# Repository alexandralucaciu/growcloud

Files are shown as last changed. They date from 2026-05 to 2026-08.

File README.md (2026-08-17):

# GrowCloud: Smart IoT Microclimate Monitoring System

An end-to-end IoT system designed to monitor and optimize the microclimate of indoor houseplants (*Spathiphyllum*). The project integrates a battery-powered edge sensing node, ThingsBoard Cloud telemetry, serverless proxy functions, and a responsive React web dashboard.

*Bachelor's Thesis Project — Politehnica University of Timișoara, Systems Engineering (Automation and Applied Informatics), July 2026.*
*Author: Alexandra Buhai (Lucaciu) | Coordinator: Ș.l.dr.ing. Paul Negîrla*

---

## System Architecture

The project follows a three-tier architecture:

1. **Edge Node (ESP32-S2 Mini):** Acquires sensor data (temperature, air humidity, ambient light, and capacitive soil moisture), provides local visual feedback via an OLED display, and transmits telemetry over MQTT every 2 hours (or on-demand via push button).
2. **Cloud Backend (ThingsBoard Cloud):** Collects and persists time-series telemetry data and manages historical logs.
3. **Serverless Layer & Web Application (React / Vite + Vercel):**
   - **Secure Serverless Proxy:** Isolates ThingsBoard credentials within backend environment variables (`process.env`). The client-side application queries internal endpoints (`/api/telemetry/latest`), preventing credential leakage.
   - **Vercel KV (Redis):** Handles persistent state tracking across serverless invocations (e.g., 24-hour soil oversaturation detection, daily user streak, and anti-duplicate email alert throttling).
   - **Automated Alerts:** Cron functions notify users via email (Resend API) when the device goes offline or critical thresholds are breached.
   - **Web Dashboard:** Displays live vs. stale data indicators, plant health status (normal, warning, critical), customized watering guides, and historical charts.

---

## Hardware Components & Enclosure

- **Microcontroller:** ESP32-S2 Mini (MicroPython runtime)
- **Environmental Sensor:** DHT22 (Air Temperature & Humidity)
- **Light Sensor:** BH1750 (I2C ambient light sensor in Lux)
- **Soil Moisture Sensor:** Capacitive Soil Moisture Sensor v2.0 (corrosion-resistant analog probe)
- **Display:** 1.3" I2C OLED Display (SH1106 driver)
- **Power Management:** 3.7V 2000 mAh Li-Po battery, TP4056 USB-C charging/protection module, 3.7V-to-5V step-up boost converter, and mechanical toggle switch
- **Enclosure:** Custom 3D-printed two-piece enclosure designed and sliced for optimal component placement and thermal isolation

---

## Firmware Features (MicroPython)

- **Digital Filtering & Soil Calibration:** 50-sample moving average filter on analog readings to suppress electrical noise. Maps inverted raw ADC values (8191 for dry air, 3320 for saturated water) to a 0–100% moisture scale.
- **Fault-Tolerant Acquisition:** Implements sentinel error values (-1) if a sensor fails, ensuring uninterrupted MQTT transmission cycles.
- **Dual Acquisition Modes:** Automated background interval transmission (every 2 hours) and instant on-demand reading triggered by a hardware button.

---

## Repository Structure

```
├── api/
│   ├── check-inactivity.js       # Vercel cron function for inactivity/offline email alerts
│   └── telemetry/
│       └── latest.js             # Secure backend proxy to ThingsBoard API
├── firmware/
│   ├── boot.py                   # Wi-Fi initialization
│   ├── main.py                   # Main sampling loop, digital filtering, and MQTT client
│   ├── sh1106.py                 # OLED display driver
│   ├── sprites.py                # Graphical UI assets for the OLED screen
│   └── umqttsimple.py            # Lightweight MQTT implementation
├── src/                          # React web application (UI components, hooks, charts)
├── public/                       # Static web assets
├── index.html                    # Web entry point
├── vercel.json                   # Vercel deployment and cron configuration
└── vite.config.js                # Vite build configuration
```

---

## Hardware / 3D Models

The enclosure and battery holder were custom-designed and sliced for optimal component placement and thermal isolation. Project files (`.3mf`, editable in Cura, PrusaSlicer, or Bambu Studio) are available in [`3d-models/`](./3d-models):

- `project base.3mf` / `project body.3mf` / `project top.3mf` — the three-part enclosure
- `battery-box1.3mf` / `battery-box2.3mf` — battery compartment

---

## Gallery & Demo

<p align="center">
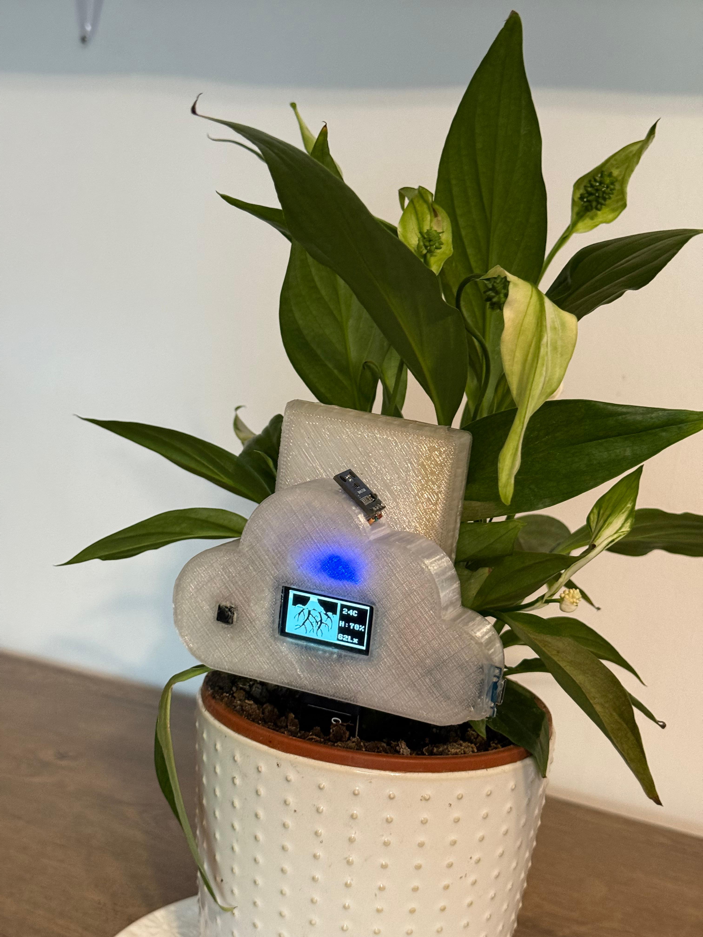
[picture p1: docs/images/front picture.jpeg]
GrowCloud device - front view
  
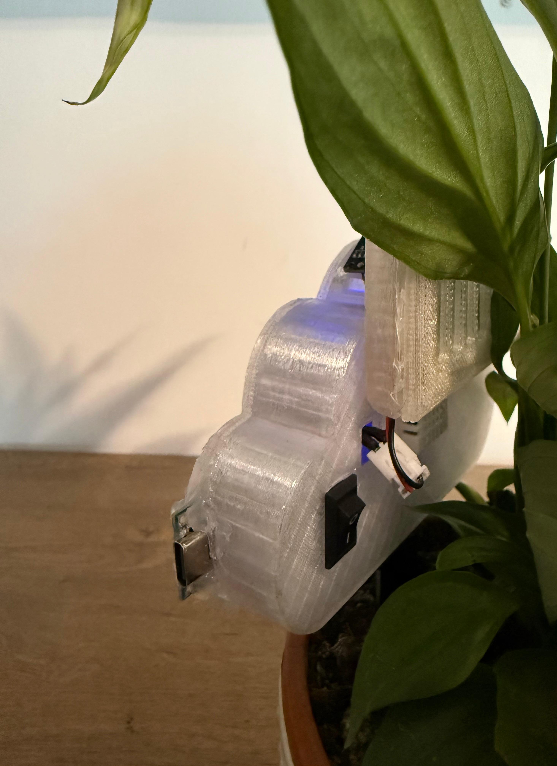
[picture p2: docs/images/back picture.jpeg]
GrowCloud device - back view
  
</p>

📹 **Demo video:** hosted on OneDrive due to file size — see [docs/video/Lucaciu_Alexandra_Video_AIA_Licenta.pdf](./docs/video/Lucaciu_Alexandra_Video_AIA_Licenta.pdf) for the link.

---

## Getting Started

### 1. Firmware Setup (ESP32-S2 Mini)

1. Flash MicroPython firmware onto the ESP32-S2 Mini using Thonny IDE or `esptool`.
2. Open `firmware/boot.py` and configure your local Wi-Fi credentials:

   ```python
   SSID = "YOUR_WIFI_SSID"
   PASS = "YOUR_WIFI_PASSWORD"
   ```

3. Open `firmware/main.py` and insert your ThingsBoard device token:

   ```python
   ACCESS_TOKEN = "YOUR_THINGSBOARD_TOKEN"
   ```

4. Upload all files from the `firmware/` directory directly to the root of the ESP32 filesystem.
5. The device connects to Wi-Fi on boot and begins periodic telemetry reporting.

### 2. Web Application Setup (Local Development)

**Prerequisites**

- Node.js 18+ (tested on Node 22)
- npm

**Environment Variables**

Create a `.env` file in the root directory and configure the required keys:

```
TB_SERVER_URL=https://thingsboard.cloud
TB_USERNAME=your_thingsboard_username
TB_PASSWORD=your_thingsboard_password
TB_DEVICE_ID=your_device_id
RESEND_API_KEY=your_resend_api_key
USER_ALERT_EMAIL=user@example.com
CRON_SECRET=your_secure_cron_secret
VERCEL_PROJECT_URL=http://localhost:5173
```

**Installation and Execution**

```bash
# Install dependencies
npm install

# Start development server
npm run dev

# Build for production
npm run build
```

The application will be accessible locally at `http://localhost:5173`.

---

## Deployment

The web dashboard and serverless endpoints are configured for continuous deployment on Vercel. Environment variables are managed securely through the Vercel project dashboard, and cron schedules in `vercel.json` run automated inactivity and health checks without requiring dedicated server infrastructure.

---

## License

This project is licensed under the MIT License — see the [LICENSE](./LICENSE) file for details.

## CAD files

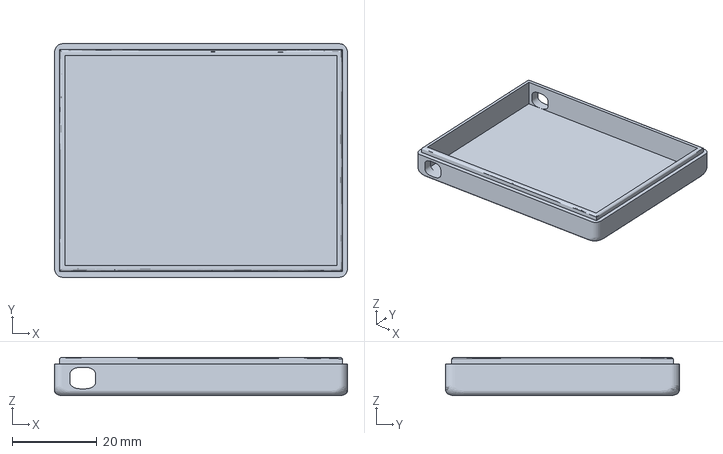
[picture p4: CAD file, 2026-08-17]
3d-models/battery-box1.3mf
69.0 x 55.0 x 9.00 mm

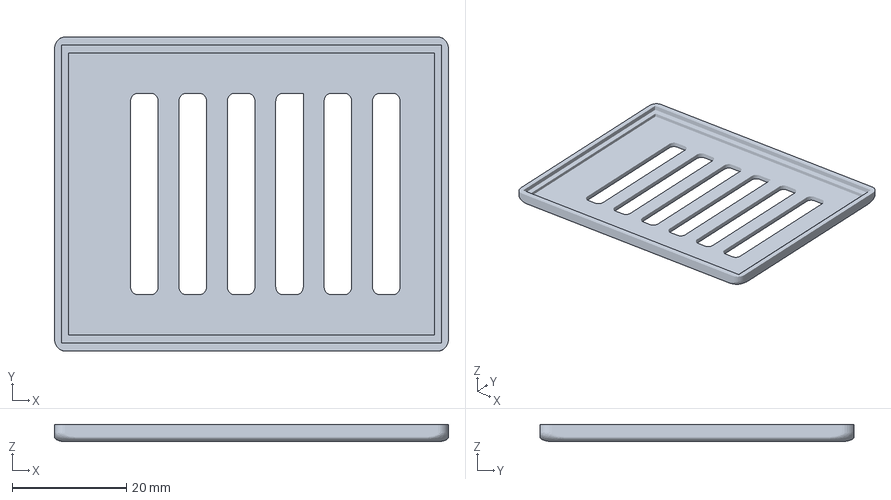
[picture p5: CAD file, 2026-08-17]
3d-models/battery-box2.3mf
69.0 x 55.0 x 3.00 mm

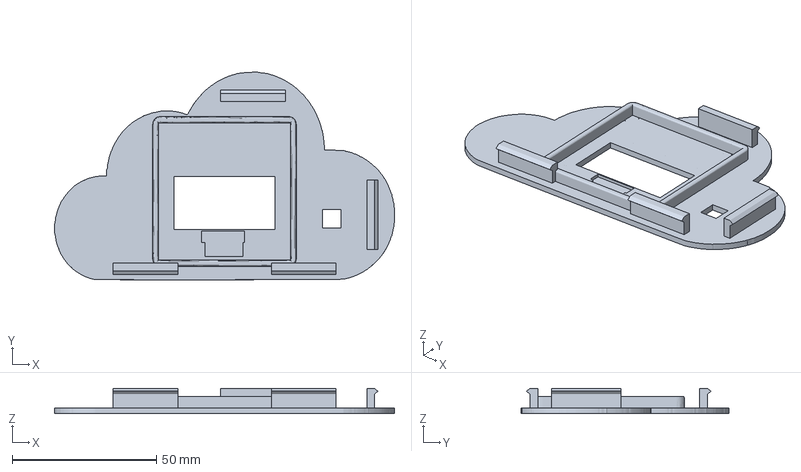
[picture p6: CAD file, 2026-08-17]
3d-models/project top.3mf
117.7 x 71.9 x 8.75 mm

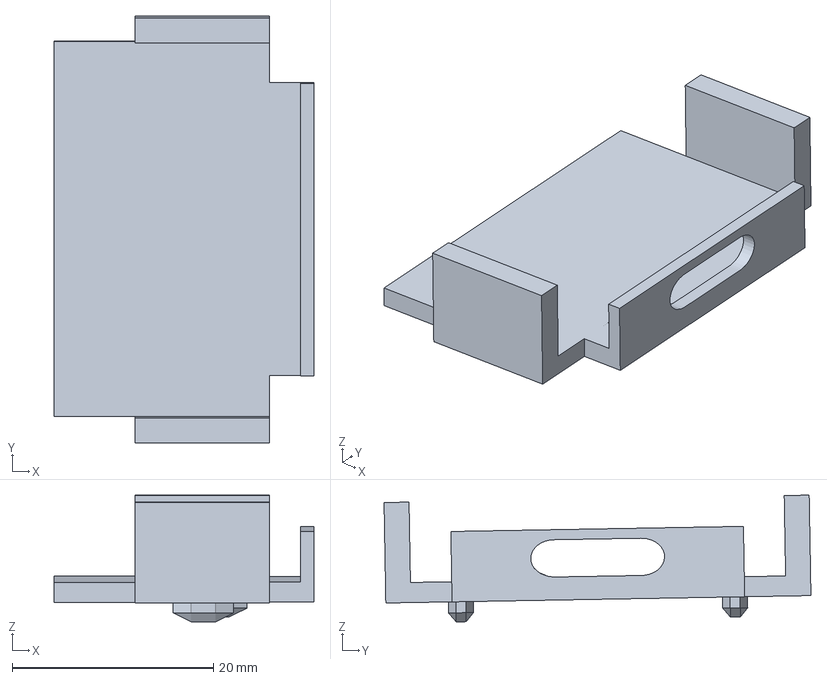
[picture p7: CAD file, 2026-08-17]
3d-models/project base.3mf
25.9 x 42.5 x 12.6 mm

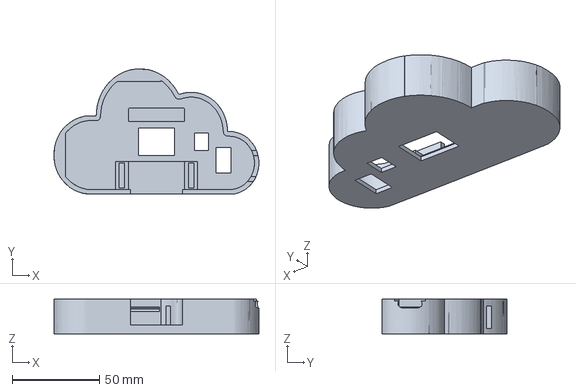
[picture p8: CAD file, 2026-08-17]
3d-models/project body.3mf
117.7 x 71.9 x 20.0 mm

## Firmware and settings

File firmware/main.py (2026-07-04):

from machine import Pin, I2C, ADC
import sh1106
from framebuf import FrameBuffer, MONO_HLSB
from sprites import root
from umqttsimple import MQTTClient
import time
import dht

# ---------------- Configurare ThingsBoard ----------------
TB_SERVER = "eu.thingsboard.cloud"
ACCESS_TOKEN = "***"   # token mascat

# ---------------- Configurare periferice ----------------
# Senzori
dht_sensor = dht.DHT22(Pin(16))

soil_adc = ADC(Pin(4))
soil_adc.width(ADC.WIDTH_13BIT)   # 0-8191
soil_adc.atten(ADC.ATTN_11DB)

# Buton (pull-up intern, tratat prin intrerupere)
button = Pin(5, Pin.IN, Pin.PULL_UP)

# Magistrala I2C comuna: OLED + BH1750
i2c = I2C(0, scl=Pin(9), sda=Pin(8), freq=400000)
BH1750_ADDR = 0x23

# ---------------- Initializare OLED ----------------
oled_functional = False
try:
    oled = sh1106.SH1106_I2C(width=128, height=64, i2c=i2c, addr=0x3c)
    oled.write_cmd(0xAE)   # Display OFF
    oled.write_cmd(0x8D)   # activare pompa de sarcina
    oled.write_cmd(0x14)
    oled.write_cmd(0xAF)   # Display ON
    oled.sleep(False)
    oled.contrast(0xFF)    # contrast maxim
    oled.fill(0)
    oled.show()
    oled_functional = True
except Exception as e:
    print("Eroare la initializarea OLED:", e)

# ---------------- Functii senzor lumina ----------------
def get_lux():
    try:
        i2c.writeto(BH1750_ADDR, b'\x10')
        time.sleep(0.2)
        data = i2c.readfrom(BH1750_ADDR, 2)
        return int((data[0] << 8 | data[1]) / 1.2)
    except:
        return -1

# ---------------- Functii desen ecran ----------------
def thick_hline(oled, x, y, width, thickness):
    for i in range(thickness):
        oled.hline(x, y + i, width, 1)

def thick_vline(oled, x, y, height, thickness):
    for i in range(thickness):
        oled.vline(x + i, y, height, 1)

def invert_fb_percent(fb, width, height, percent):
    percent = max(0, min(100, percent))
    lines_to_invert = int(height * percent / 100)
    for y in range(height - lines_to_invert, height):
        for x in range(width):
            current = fb.pixel(x, y)
            fb.pixel(x, y, 1 - current)

# ---------------- Control afisaj ----------------
ecran_pornit = True
timp_stingere_ecran = time.ticks_ms()

def aprinde_ecran():
    global ecran_pornit, timp_stingere_ecran
    if oled_functional:
        oled.write_cmd(0xAF)                            # pornire afisaj
        ecran_pornit = True
        timp_stingere_ecran = time.ticks_ms() + 10000   # ramane aprins 10 s

def stinge_ecran():
    global ecran_pornit
    if oled_functional:
        oled.write_cmd(0xAE)                            # stingere afisaj (consum minim)
        ecran_pornit = False

def button_pressed_handler(pin):
    aprinde_ecran()

# Declansare pe front descendent (butonul face contact la GND)
button.irq(trigger=Pin.IRQ_FALLING, handler=button_pressed_handler)

# ---------------- Functie desenare cadru ----------------
def deseneaza_ecran(t, h, lux, soil_moisture):
    oled.fill(0)

    root_copy = bytearray(root)
    fb_root = FrameBuffer(root_copy, 80, 64, MONO_HLSB)
    invert_fb_percent(fb_root, 80, 64, soil_moisture)
    oled.blit(fb_root, 0, 0)

    # Chenare
    thick_vline(oled, 0, 0, 64, 3)
    thick_vline(oled, 77, 0, 64, 3)
    thick_vline(oled, 125, 0, 64, 3)
    thick_hline(oled, 0, 0, 128, 3)
    thick_hline(oled, 0, 61, 128, 3)

    # Text
    oled.text(f"{t}C", 85, 10)
    oled.text(f"H:{h}%", 82, 30)
    if lux > 999:
        oled.text(f"{lux//1000}kLx", 82, 50)
    else:
        oled.text(f"{lux}Lx", 82, 50)
    oled.show()

# ---------------- Bucla principala ----------------
INTERVAL_CLOUD = 2 * 60 * 60 * 1000                        # 2 ore, in milisecunde
ultima_trimitere_cloud = time.ticks_ms() - INTERVAL_CLOUD  # forteaza prima trimitere la boot

print("Incepem monitorizarea...")

while True:
    try:
        timp_curent = time.ticks_ms()

        # --- Mod automat: transmitere la fiecare 2 ore ---
        if time.ticks_diff(timp_curent, ultima_trimitere_cloud) >= INTERVAL_CLOUD:
            aprinde_ecran()                                # indicator vizual al transmisiei

            try:
                dht_sensor.measure()
                t, h = int(dht_sensor.temperature()), int(dht_sensor.humidity())
            except:
                t, h = -1, -1                              # valoare-santinela in caz de eroare

            lux = get_lux()

            suma_sol = 0
            for _ in range(50):                            # mediere pe 50 de esantioane
                suma_sol += soil_adc.read()
                time.sleep(0.01)
            val_raw = int(suma_sol / 50)
            soil_moisture = max(0, min(100, ((8191 - val_raw) * 100) // (8191 - 3320)))

            # Publicare telemetrie prin MQTT
            try:
                client = MQTTClient("ESP32S2_Final_Test", TB_SERVER, user=ACCESS_TOKEN, password="")
                client.connect()                           # port 1883, fara TLS (implicit)
                payload = '{"temperature":%d, "humidity":%d, "soil":%d, "light":%d}' % (t, h, soil_moisture, lux)
                client.publish("v1/devices/me/telemetry", payload)
                client.disconnect()                        # inchide socketul (sesiune scurta)
            except Exception as mqtt_err:
                print("[CLOUD] Eroare la trimiterea MQTT:", mqtt_err)

            ultima_trimitere_cloud = time.ticks_ms()

        # --- Stingerea automata a ecranului dupa 10 s ---
        if ecran_pornit and time.ticks_diff(time.ticks_ms(), timp_stingere_ecran) >= 0:
            stinge_ecran()

        # --- Reimprospatarea afisajului cat timp e pornit ---
        if ecran_pornit:
            try:
                dht_sensor.measure()
                t, h = int(dht_sensor.temperature()), int(dht_sensor.humidity())
            except:
                t, h = -1, -1

            lux = get_lux()

            suma_sol = 0
            for _ in range(20):                            # mediere mai usoara pentru afisaj
                suma_sol += soil_adc.read()
                time.sleep(0.01)
            val_raw = int(suma_sol / 20)
            soil_moisture = max(0, min(100, ((8191 - val_raw) * 100) // (8191 - 3320)))

            if oled_functional:
                deseneaza_ecran(t, h, lux, soil_moisture)

    except Exception as e:
        print("Eroare in loop:", e)

    time.sleep(0.1)

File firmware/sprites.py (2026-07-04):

root = bytearray([0xff, 0xff, 0xff, 0xff, 0xff, 0xff, 0xff, 0xff, 0xff, 0xff, 0xff, 0xff, 0xff, 0xff, 0xff, 0xff, 
    0xff, 0xff, 0xff, 0xff, 0xff, 0xff, 0xff, 0xff, 0xff, 0xff, 0xff, 0xff, 0xff, 0xff, 0xe0, 0x00, 
    0x00, 0x00, 0xff, 0xe0, 0x00, 0x00, 0x00, 0x07, 0xe0, 0x00, 0x00, 0x00, 0xff, 0xe0, 0x00, 0x00, 
    0x00, 0x07, 0xe0, 0x00, 0x00, 0x00, 0xff, 0xe0, 0x00, 0x00, 0x00, 0x07, 0xe0, 0x00, 0x00, 0x00, 
    0xff, 0xe0, 0x00, 0x00, 0x00, 0x07, 0xe0, 0x00, 0x00, 0x00, 0xff, 0xf0, 0x00, 0x00, 0x00, 0x07, 
    0xe0, 0x00, 0x00, 0x00, 0xff, 0xf0, 0x00, 0x00, 0x00, 0x07, 0xe0, 0x00, 0x00, 0x01, 0xff, 0xf0, 
    0x00, 0x00, 0x00, 0x07, 0xe0, 0x00, 0x00, 0x01, 0xff, 0xf8, 0x00, 0x00, 0x00, 0x07, 0xe0, 0x00, 
    0x00, 0x03, 0xff, 0xfc, 0x00, 0x00, 0x00, 0x07, 0xe0, 0x00, 0x00, 0x03, 0xff, 0xfe, 0x00, 0x00, 
    0x00, 0x07, 0xe0, 0x00, 0x00, 0x07, 0xff, 0xff, 0x00, 0x00, 0x00, 0x07, 0xe0, 0x00, 0x00, 0x07, 
    0xff, 0xff, 0x80, 0x00, 0x00, 0x07, 0xe0, 0x00, 0x00, 0x0f, 0xff, 0xff, 0xe0, 0x00, 0x00, 0x07, 
    0xe0, 0x00, 0x00, 0x0f, 0xff, 0xff, 0xf8, 0x00, 0x00, 0x07, 0xe0, 0x00, 0x00, 0x1f, 0xff, 0xff, 
    0xfc, 0x00, 0x00, 0x07, 0xe0, 0x00, 0x00, 0x3f, 0xff, 0xff, 0xfc, 0x00, 0x00, 0x07, 0xe0, 0x03, 
    0xe0, 0x7f, 0xfe, 0xff, 0xfe, 0x00, 0x00, 0x07, 0xe0, 0x0f, 0xff, 0xff, 0xfc, 0x3f, 0xff, 0x00, 
    0x00, 0x07, 0xe0, 0x1f, 0xff, 0xfb, 0xf8, 0x1f, 0xff, 0x81, 0xf0, 0x07, 0xe0, 0x30, 0x03, 0xe3, 
    0xf0, 0x07, 0xc7, 0xc7, 0xf8, 0x07, 0xe0, 0x40, 0x07, 0xc3, 0xf0, 0x03, 0xe3, 0xff, 0x0e, 0x07, 
    0xe0, 0x80, 0x07, 0x83, 0xe0, 0x03, 0xe1, 0xfe, 0x02, 0x07, 0xe0, 0x00, 0x0f, 0x03, 0xe0, 0x01, 
    0xf0, 0xff, 0x81, 0x07, 0xe0, 0x00, 0x1e, 0x03, 0xe0, 0x00, 0xf0, 0x3f, 0xc1, 0x07, 0xe0, 0x00, 
    0x3e, 0x03, 0xe0, 0x00, 0x78, 0x0f, 0xf0, 0x07, 0xe0, 0x00, 0x3f, 0x03, 0xf0, 0x00, 0x78, 0x03, 
    0xf0, 0x07, 0xe0, 0x00, 0x7b, 0x03, 0xfc, 0x00, 0x3c, 0x07, 0xf8, 0x07, 0xe0, 0x00, 0xf3, 0x83, 
    0xfe, 0x1c, 0x3c, 0x06, 0x3c, 0x07, 0xe0, 0x01, 0xf1, 0x83, 0xcf, 0x32, 0x3c, 0x06, 0x1c, 0x07, 
    0xe0, 0x03, 0xe1, 0xc3, 0xc7, 0xe0, 0x1e, 0x04, 0x0e, 0x07, 0xe0, 0x03, 0xe0, 0xc3, 0xc3, 0xe0, 
    0x1e, 0x04, 0x0e, 0x07, 0xe0, 0x05, 0xc0, 0xc7, 0xc0, 0xf0, 0x1e, 0x08, 0x06, 0x07, 0xe0, 0x09, 
    0xc0, 0x47, 0x80, 0x78, 0x3e, 0x10, 0x06, 0x07, 0xe0, 0x11, 0x80, 0x47, 0x80, 0x3c, 0x7e, 0x00, 
    0x02, 0x07, 0xe0, 0x21, 0x80, 0x4f, 0xc0, 0x1e, 0xff, 0xc0, 0x02, 0x07, 0xe0, 0x21, 0x80, 0x4f, 
    0xc0, 0x0f, 0xdf, 0xfe, 0x02, 0x07, 0xe0, 0x61, 0x00, 0x5e, 0xe0, 0x1f, 0x9f, 0xff, 0x02, 0x07, 
    0xe0, 0x41, 0x00, 0xbe, 0x78, 0xcf, 0x9e, 0x0f, 0x82, 0x07, 0xe0, 0x41, 0x00, 0x3c, 0x3f, 0x8b, 
    0x9e, 0x09, 0xc2, 0x07, 0xe0, 0x01, 0x00, 0x78, 0x1e, 0x0b, 0xbc, 0x08, 0xc2, 0x07, 0xe0, 0x01, 
    0x00, 0xf8, 0x0f, 0x0b, 0xbc, 0x08, 0x46, 0x07, 0xe0, 0x01, 0x00, 0xf0, 0x07, 0x86, 0xbc, 0x00, 
    0x46, 0x07, 0xe0, 0x00, 0x01, 0xf0, 0x07, 0x84, 0xf8, 0x00, 0x44, 0x07, 0xe0, 0x00, 0x01, 0xe0, 
    0x03, 0xc4, 0xf8, 0x00, 0x20, 0x07, 0xe0, 0x00, 0x03, 0xf0, 0x01, 0xc4, 0xf8, 0x00, 0x20, 0x07, 
    0xe0, 0x00, 0x03, 0xf8, 0x01, 0xc0, 0xf8, 0x00, 0x20, 0x07, 0xe0, 0x00, 0x07, 0xb8, 0x00, 0xc1, 
    0xee, 0x00, 0x20, 0x07, 0xe0, 0x01, 0xff, 0x1c, 0x00, 0xc1, 0xe7, 0x00, 0x00, 0x07, 0xe0, 0x07, 
    0x1e, 0x1e, 0x01, 0xe1, 0xc3, 0x00, 0x00, 0x07, 0xe0, 0x0c, 0x1c, 0x0e, 0x01, 0x61, 0xc3, 0x80, 
    0x00, 0x07, 0xe0, 0x00, 0x38, 0x0e, 0x02, 0x61, 0x81, 0x80, 0x00, 0x07, 0xe0, 0x00, 0x70, 0x07, 
    0x04, 0x61, 0x81, 0x80, 0x00, 0x07, 0xe0, 0x01, 0xc0, 0x07, 0x04, 0x61, 0x80, 0xc0, 0x00, 0x07, 
    0xe0, 0x03, 0x00, 0x03, 0x08, 0x21, 0x80, 0x80, 0x00, 0x07, 0xe0, 0x0e, 0x00, 0x03, 0x08, 0x01, 
    0x80, 0x80, 0x00, 0x07, 0xe0, 0x08, 0x00, 0x03, 0x00, 0x00, 0x80, 0x80, 0x00, 0x07, 0xe0, 0x00, 
    0x00, 0x03, 0x00, 0x00, 0xc0, 0x80, 0x00, 0x07, 0xe0, 0x00, 0x00, 0x02, 0x00, 0x00, 0x40, 0x00, 
    0x00, 0x07, 0xff, 0xff, 0xff, 0xff, 0xff, 0xff, 0xff, 0xff, 0xff, 0xff, 0xff, 0xff, 0xff, 0xff, 
    0xff, 0xff, 0xff, 0xff, 0xff, 0xff, 0xff, 0xff, 0xff, 0xff, 0xff, 0xff, 0xff, 0xff, 0xff, 0xff
    
    ])

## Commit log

2026-05-19 Improve overview, device page, and telemetry wording
2026-05-29 Enhance inactivity check with device ID validation
2026-06-18 Remove battery data from telemetry response
2026-06-18 Remove battery assessment from plant health checks
    Removed battery status checks from plant health assessment.
2026-06-18 Remove device battery information from Overview
    Removed device battery display and related GaugeBar component.
2026-06-18 Remove battery telemetry from PlantHealth component
    Removed battery telemetry display from PlantHealth.
2026-06-18 Remove 'Low Battery' status from StatusBadge
2026-06-18 Add DataSourceBadge component for data source indication
    This component displays a badge indicating the source of the data, either as live data from a device or as mock data in development mode.
2026-07-04 Implement SH1106 OLED driver for MicroPython
    Add MicroPython SH1106 OLED driver with I2C and SPI support
2026-08-17 Create stl
